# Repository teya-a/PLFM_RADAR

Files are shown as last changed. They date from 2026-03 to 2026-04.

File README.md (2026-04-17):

# AERIS-10: Open Source Pulse Linear Frequency Modulated Phased Array Radar







AERIS-10 is an open-source, low-cost 10.5 GHz phased array radar system featuring Pulse Linear Frequency Modulated (LFM) modulation. Available in two versions (3km and 20km range), it's designed for researchers, drone developers, and serious SDR enthusiasts who want to explore and experiment with phased array radar technology.

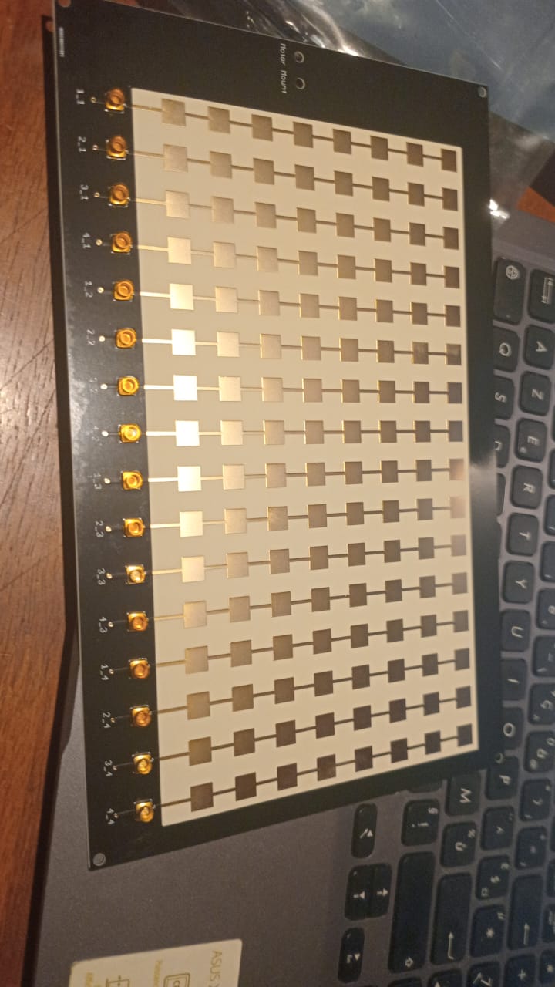
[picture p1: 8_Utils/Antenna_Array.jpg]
AERIS-10 Antenna Array


## 📡 Overview

The AERIS-10 project aims to democratize radar technology by providing a fully open-source, modular, and hackable radar system. Whether you're a university researcher, a drone startup, or an advanced maker, AERIS-10 offers a platform for experimenting with beamforming, pulse compression, Doppler processing, and target tracking.

## 🔬 Key Features

- **Open Source Hardware & Software** - Complete schematics, PCB layouts, firmware, and software available
- **Dual Version Availability**:
  - **AERIS-10N (Nexus)**: 3km range with 8x16 patch antenna array
  - **AERIS-10E (Extended)**: 20km range with 32x16 dielectric-filled slotted waveguide array
- **Full Electronic Beam Steering** - ±45° electronic steering in elevation and azimuth
- **Advanced Signal Processing** - On-board FPGA handles pulse compression, Doppler FFT, MTI, and CFAR
- **Python GUI** - User-friendly interface with map integration
- **GPS/IMU Integration** - Real-time position and attitude correction
- **Modular Design** - Separate power management, frequency synthesis, and RF boards

## 🏗️ System Architecture

AERIS-10 System Diagram

### Hardware Components

The AERIS-10 main sub-systems are:

- **Power Management Board** - Supplies all necessary voltage levels to the electronics components with proper filtering and sequencing (sequencing ensured by the microcontroller)

- **Frequency Synthesizer Board** - Uses a high-performance Low Jitter Clock Generator (AD9523-1) that supplies phase-aligned clock references for:
  - RX and TX Frequency Synthesizers (ADF4382)
  - DAC
  - ADC
  - FPGA

- **Main Board** containing:
  - **DAC** - Generates the RADAR Chirps
  - **2x Microwave Mixers (LT5552)** - For up-conversion and IF-down-conversion
  - **4x 4-Channel Phase Shifters (ADAR1000)** - For RX and TX chain beamforming
  - **16x Front End Chips (ADTR1107)** - Used for both Low Noise Amplifying (RX) and Power Amplifying (TX) stages
  - **XC7A50T FPGA** - Handles RADAR Signal Processing on the upstream FTG256 board:
    - PLFM Chirps generation via the DAC
    - Raw ADC data read
    - Automatic Gain Control (AGC)
    - I/Q Baseband Down-Conversion
    - Decimation
    - Filtering
    - Forward FFT
    - Pulse Compression
    - Doppler, MTI and CFAR processing
    - USB Interface
  - **STM32F746xx Microcontroller** - Used for:
    - Power-up and power-down sequencing (see Power Management Excel File)
    - FPGA communication
    - Setup and Interface with:
      - Clock Generator (AD9523-1)
      - 2x Frequency Synthesizers (ADF4382)
      - 4x 4-Channel Phase Shifters (ADAR1000) for RADAR pulse sequencing
      - 2x ADS7830 ADCs (on Power Amplifier Boards) for Idq measurement
      - 2x DAC5578 (on Power Amplifier Boards) for Vg control
      - GPS module for GUI map centering
      - GY-85 IMU for pitch/roll correction of target coordinates
      - BMP180 Barometer
      - Stepper Motor
      - 8x ADS7830 Temperature Sensors for cooling fan control
      - RF switches

- **16x Power Amplifier Boards** - Used only for AERIS-10E version, featuring 10Watt QPA2962 GaN amplifier for extended range

- **Antenna Arrays**:
  - **AERIS-10N (Nexus)** - 8x16 patch antenna array
  - **AERIS-10X (Extended)** - 32x16 dielectric-filled slotted waveguide antenna array

- **Miscellaneous Components**:
  - Slip-Ring
  - Stepper Motor and drivers
  - Cooling Fans
  - Enclosure

### Processing Pipeline

1. **Waveform Generation** - DAC creates LFM chirps
2. **Up/Down Conversion** - LT5552 mixers handle frequency translation
3. **Beam Steering** - ADAR1000 phase shifters control 16 elements
4. **Signal Processing (FPGA)**:
   - Raw ADC data capture
   - I/Q baseband down-conversion
   - Decimation & filtering (CIC/FIR)
   - Pulse compression
   - Doppler FFT processing
   - MTI & CFAR detection
5. **System Management (STM32)**:
   - Power sequencing
   - Peripheral configuration
   - GPS/IMU integration
   - Stepper motor control
6. **Visualization (Python GUI)**:
   - Real-time target plotting
   - Map integration
   - Radar control interface

AERIS-10 GUI Demo

## 📊 Technical Specifications

| Parameter | AERIS-10N (Nexus) | AERIS-10X (Extended) |
|---|---|---|
| **Frequency** | 10.5 GHz | 10.5 GHz |
| **Max Range** | 3 km | 20 km |
| **Antenna** | 8x16 Patch Array | 32x16 Slotted Waveguide |
| **Beam Steering** | Electronic (±45°) | Electronic (±45°) |
| **Mechanical Scan** | 360° (stepper motor) | 360° (stepper motor) |
| **Output Power** | ~1W×16 | 10W×16 (GaN amplifier) |
| **Processing** | FPGA + STM32 | FPGA + STM32 |

## 🚀 Getting Started

### 🧹 Repository File Placement Policy

To keep the repository root clean and make artifacts easy to find, place generated files in the following locations:

- **Published reports (tracked, GitHub Pages):** `docs/`
  - Example: `docs/AERIS_Simulation_Report_v2.pdf`
- **Simulation-generated outputs (local, gitignored):** `5_Simulations/generated/`
  - Plots, scenario outputs, temporary analysis directories
- **FPGA/Vivado generated artifacts (local, gitignored):** `9_Firmware/9_2_FPGA/reports/`
  - VCD/VVP dumps, temporary CSVs, local report snapshots
- **Reusable FPGA automation scripts (tracked):** `9_Firmware/9_2_FPGA/scripts/`
  - TCL flows, helper scripts used by build/bring-up

**Do not leave generated artifacts in the repository root.**

### Prerequisites

- Basic understanding of radar principles
- Experience with PCB assembly (for hardware build)
- Python 3.8+ for the GUI software
- FPGA development tools (Vivado) for signal processing modifications

### Hardware Assembly

1. **Order PCBs**: Production outputs are under `/4_Schematics and Boards Layout/4_7_Production Files`
2. **Source Components**: BOM/CPL files are co-located under `/4_Schematics and Boards Layout/4_7_Production Files`
3. **Assembly**: Use the schematics in `/4_Schematics and Boards Layout/4_6_Schematics` together with the production outputs above; a standalone assembly guide is not currently tracked
4. **Antenna**: Choose appropriate array files for your target variant
5. **Enclosure**: Mechanical drawings currently live in `/8_Utils/Mechanical_Drawings`

## 📜 License

This project is open-source but uses **different licenses for hardware and software** to ensure proper legal coverage.

### Hardware Documentation
The hardware design files—including:
- Schematics and PCB layouts (in `/4_Schematics and Boards Layout`)
- Bill of Materials (BOM) files
- Gerber files and manufacturing outputs
- Mechanical drawings and enclosure designs

are licensed under the **CERN Open Hardware Licence Version 2 – Permissive (CERN-OHL-P)** .

This is a hardware-specific license that:
- ✅ Clearly defines "Hardware," "Documentation," and "Products"
- ✅ Includes explicit patent protection for contributors and users
- ✅ Provides stronger liability limitations (important for high-power RF)
- ✅ Aligns with professional open-hardware standards (CERN, OSHWA)

You may use, modify, and sell products based on these designs, provided you:
- Maintain the original copyright notices
- Distribute any modified designs under the same license
- Make your modifications available in Source format

### Software and Firmware
The software components—including:
- FPGA code (VHDL/Verilog in `/9_Firmware`)
- Microcontroller firmware (STM32)
- Python GUI and utilities

remain under the **MIT License** for maximum flexibility.

### Full License Texts
- The complete CERN-OHL-P license text is in the `LICENSE` file
- MIT license terms apply to software where not otherwise specified

### Why This Change?
Originally, the entire project used the MIT license. The community (special thanks to gmaynez!) pointed out that MIT lacks legal protections needed for physical hardware. The switch to CERN-OHL-P ensures the project is properly protected while maintaining the same permissive spirit.

## 📚 Documentation

Comprehensive documentation is available in the `/docs` folder and served via GitHub Pages at [https://NawfalMotii79.github.io/PLFM_RADAR/docs/](https://NawfalMotii79.github.io/PLFM_RADAR/docs/):

- [System Architecture](/docs/architecture.html)
- [Implementation Log](/docs/implementation-log.html)
- [Hardware Bring-Up Guide](/docs/bring-up.html)
- [Test Reports](/docs/reports.html)
- [Release Notes](/docs/release-notes.html)

## 🤝 Contributing

We welcome contributions! Please see our [Contributing Guidelines](/CONTRIBUTING.md) for details on repo layout, branch workflow, and basic PR checks.

Areas where help is especially appreciated:
- **RF Engineers**: Review designs, optimize antenna performance
- **FPGA Developers**: Optimize signal processing pipeline
- **Software Developers**: Enhance Python GUI and SDK
- **Beta Testers**: University researchers, drone startups, advanced makers

## 📞 Contact & Collaboration

I welcome serious inquiries from researchers, engineers, and potential collaborators. However, due to the high volume of interest in this project, please understand that I cannot guarantee a response to every message.

- **Technical questions or bug reports**: Please [open a GitHub issue](https://github.com/NawfalMotii79/PLFM_RADAR/issues) so the whole community can benefit from the discussion.
- **Collaboration, licensing, or business inquiries**: 📧 nawfal.motii.33 [at] gmail [dot] com

## 💰 Sponsors

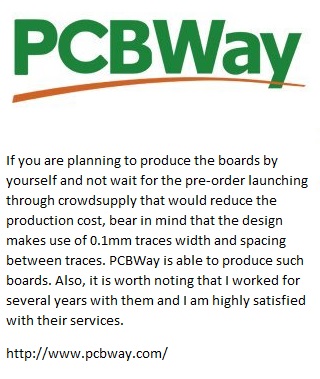
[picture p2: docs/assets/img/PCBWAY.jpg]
PCBWay Sponsor Logo


---

**Star ⭐ this repository if you're interested in open-source radar technology!**

*Note: This is an active development project. Some features are still in progress. Check the issues page for known limitations and upcoming features.*

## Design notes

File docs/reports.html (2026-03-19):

AERIS-10 Docs

Artifacts

# Published Reports and Visuals

Central access point for antenna simulations, implementation summaries, timing baselines, and board-day artifact references.

Open Board-Day Worksheet Open Bring-Up Plan

## Current FPGA implementation status

- Build 15 is the current detailed analysis baseline for the production XC7A200T target and completed with all timing constraints met.
- Build 16 was validated in the remote Vivado workspace as a constraint-cleanup pass: XDCB-5 warnings were removed, the large TIMING-18 bucket collapsed to a single ft601_txe methodology residue, and routed timing remained clean at WNS +0.058 ns, WHS +0.068 ns, WPWS +0.684 ns.
- The remaining ft601_txe methodology item currently behaves like an async-status-observation residue rather than a proven unconstrained functional FT601 path.

## Board-day artifact inventory

Artifact | Source path | Day-0 use | Status / note
Production-target XDC | 9_Firmware/9_2_FPGA/constraints/xc7a200t_fbg484.xdc | Constraint source of truth for the production FPGA target | Tracked and validated after Build 16 cleanup port
FPGA programming flow | 9_Firmware/9_2_FPGA/scripts/program_fpga.tcl | Programs the device and reports DONE / INIT_COMPLETE / probes presence | Primary operator-facing programming script
Debug probe insertion flow | 9_Firmware/9_2_FPGA/scripts/insert_ila_probes.tcl | Used when generating or refreshing debug-capable images | Keep matched with the selected debug bitstream
FPGA regression runner | 9_Firmware/9_2_FPGA/run_regression.sh | Pre-arrival regression evidence for the tracked FPGA baseline | 18 / 18 passing on the current tracked branch
MCU regression harness | 9_Firmware/9_1_Microcontroller/tests/Makefile | Pre-arrival firmware regression evidence before flashing hardware | 15 / 15 passing on the current tracked branch
Bring-up logging macros | 9_Firmware/9_1_Microcontroller/9_1_1_C_Cpp_Libraries/diag_log.h | Defines the main first-power-on log vocabulary used over USART3 | Observation-only instrumentation layer
Board-day worksheet | docs/board-day-worksheet.html | Record pass/fail, measurements, and blockers during first sessions | Use with this page and the bring-up plan
Bring-up execution plan | docs/bring-up.html | Operator checklist, abort criteria, observability targets, and open risks | Primary readiness document

## Antenna Simulation Report

Status: Mostly current (historical Phase-0 context)

File: AERIS_Antenna_Report.pdf

Notes: Valid for 10.5 GHz patch-element simulation and array projection context. Treat as element-level evidence, not full current hardware bring-up sign-off.

Open PDF Download

## Python Simulation Report

Status: Legacy (needs refresh)

File: AERIS_Simulation_Report.pdf

Notes: Contains older architecture assumptions (e.g., XC7A100T-centric narrative). Use as historical reference only until Simulation Report v2 is published.

Open PDF Download

## FPGA implementation analysis

Status: Current engineering baseline

Primary detailed write-up: internal Build 15 implementation analysis captured timing, power, route status, DRC, methodology, CDC, and utilization for the production-target design after USB range wiring and CFAR cleanup.

Follow-on Build 16 remote validation focused on production XDC cleanup only and confirmed no timing regression while reducing methodology noise substantially.

## Latest Simulation Report (Recommended)

Status: Current baseline (v2)

File: AERIS_Simulation_Report_v2.pdf

Aligned to the active project baseline: XC7A200T target, firmware regression closure, FPGA regression/timing gates, USB range-profile integration, and TE0712/TE0713 split-target flow.

Open PDF Download

## Report Currency Notice

- The current routed production-target baseline is Build 15, with Build 16 used as a remote-only XDC cleanup validation pass.
- The latest public simulation PDF should be interpreted alongside the implementation log and release notes for the most accurate state of firmware bug closure and FPGA integration readiness.
- Detailed Build 15 and Build 16 engineering notes currently live in internal working reports and remote Vivado artifacts rather than this public docs directory.
- The artifact inventory above is intended to stabilize day-0 execution even when the detailed internal engineering reports stay outside the public docs site.

## Antenna concept snapshot

Antenna array concept

Add future report artifacts here to keep public references stable.

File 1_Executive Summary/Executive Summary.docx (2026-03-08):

TITLE: Open Source Pulse Linear Frequency Modulated Phased Array RADAR
Reference:
Date:
Original Proposal Date:

## 1.0 PROJECT DESCRIPTION

An open-source, low-cost 10.5 GHz phased array radar with phased array antenna and Pulse LFM modulation—available in 3km and 20km range versions. For researchers, drone developers, and serious SDR enthusiasts.

## 2.0 TECHNICAL SPECIFICATIONS

### 2.1 System Architecture Overview

- The AERIS-10 comes in 2 versions:
  - AERIS-10N (Nexus) with Range up to 3Km
  - AERIS-10X (Extended) with scanning Range up to 20Km
- Frequency: 10.5GHz
- Antenna Type: 8x16 patch antenna array for the Nexus and 32x16 dielectric-filled slotted waveguide antenna array for the Extended version.
- Electronically controlled Elevation and Azimuth Beam steering. (The prototype uses the 16 antenna elements to steer the Azimuth beam and the Elevation is performed using a stepper motor; but the designed system can be hacked to control both Elevation and Azimuth electronically.
- Output: Range & Doppler of Multi-Targets
- Interface: A GUI written in Python

Current Status: Alpha Prototype

For sake of testing, validating and optimizing the cost of the prototype, this late has been designed using one PCB for:
- The Power supply management
- The Digital components
- The Analog and mixed signal components
- The RF parts

This won’t be the case for the mass production system, where separated modules would be used to reduce EMI and enhance the signals integrity; also a more professional clock source and frequency synthesizer would be used. The new schematics, PCB layout and firmware are already available

Understanding the System Hardware:

The AERIS-10 main sub-systems are:

- A Power Management Board that supplies all the necessary voltage levels to the electronics components with proper filtering and sequencing (This late is ensured by the microcontroller)
- A Frequency Synthesizer Board using a high performance Low Jitter Clock Generator (AD9523-1) that supplies phased aligned clock references for the:
  - RX and TX Frequency Synthesizers (ADF4382)
  - DAC
  - ADC
  - FPGA
- A Main Board containing:
  - A DAC to generate the RADAR Chirps
  - 2 Microwave Mixers (LT5552) for up-conversion and IF-down-conversion
  - 4 4-Channels Phase Shifters (ADAR1000) for the RX and TX chain
  - 16 Front End chips (ADTR1107) used for Both Low Noise Amplifying (RX) and Power Amplifying (TX) Stages
  - An XC7A100T FPGA used for RADAR Signal Processing:
    - PLFM Chirps generation via the DAC
    - Raw ADC data read
    - AGC
    - I/Q Baseband Down-Conversion
    - Decimation
    - Filtering
    - Forward FFT
    - Pulse Compression
    - Doppler, MTI and CFAR processing
    - USB Interface
  - An STM32F746xx Microcontroller used to:
    - Ensure the proper powering up and down sequencing (Check the Power Management Excel File)
    - Communicate with the FPGA
    - Setup and Interface with the following components:
      - The Clock Generator (AD9523-1)
      - The 2 Frequency Synthesizers (ADF4382)
      - The 4 4-Channels Phase Shifters (ADAR1000) for proper RADAR pulse sequencing
      - The 2 ADS7830 ADCs used on the 16 Power Amplifier Boards to measure Idq
      - The 2 DAC5578 used on the 16 Power Amplifier Boards to control Vg
      - The GPS used to set the center of the map on the GUI
      - The GY_85 IMU to apply pitch and roll correction to the processed target longitude and latitude
      - The BMP180 Barometer
      - The Stepper Motor
      - The 8 ADS7830 Temperature Sensors used to activate the Cooling Fans
      - RF switches
- 16 Power Amplifier Boards used only for the AERIS-10E where a 10Watt QPA2962 GaN amplifier has been chosen to extend the RADAR Range
- 8x16 patch antenna array board for the Nexus and 32x16 dielectric-filled slotted waveguide antenna array for the Extended version
- Miscellaneous (Slip-Ring, Stepper Motor and its drivers, Cooling Fan, Enclosure…)

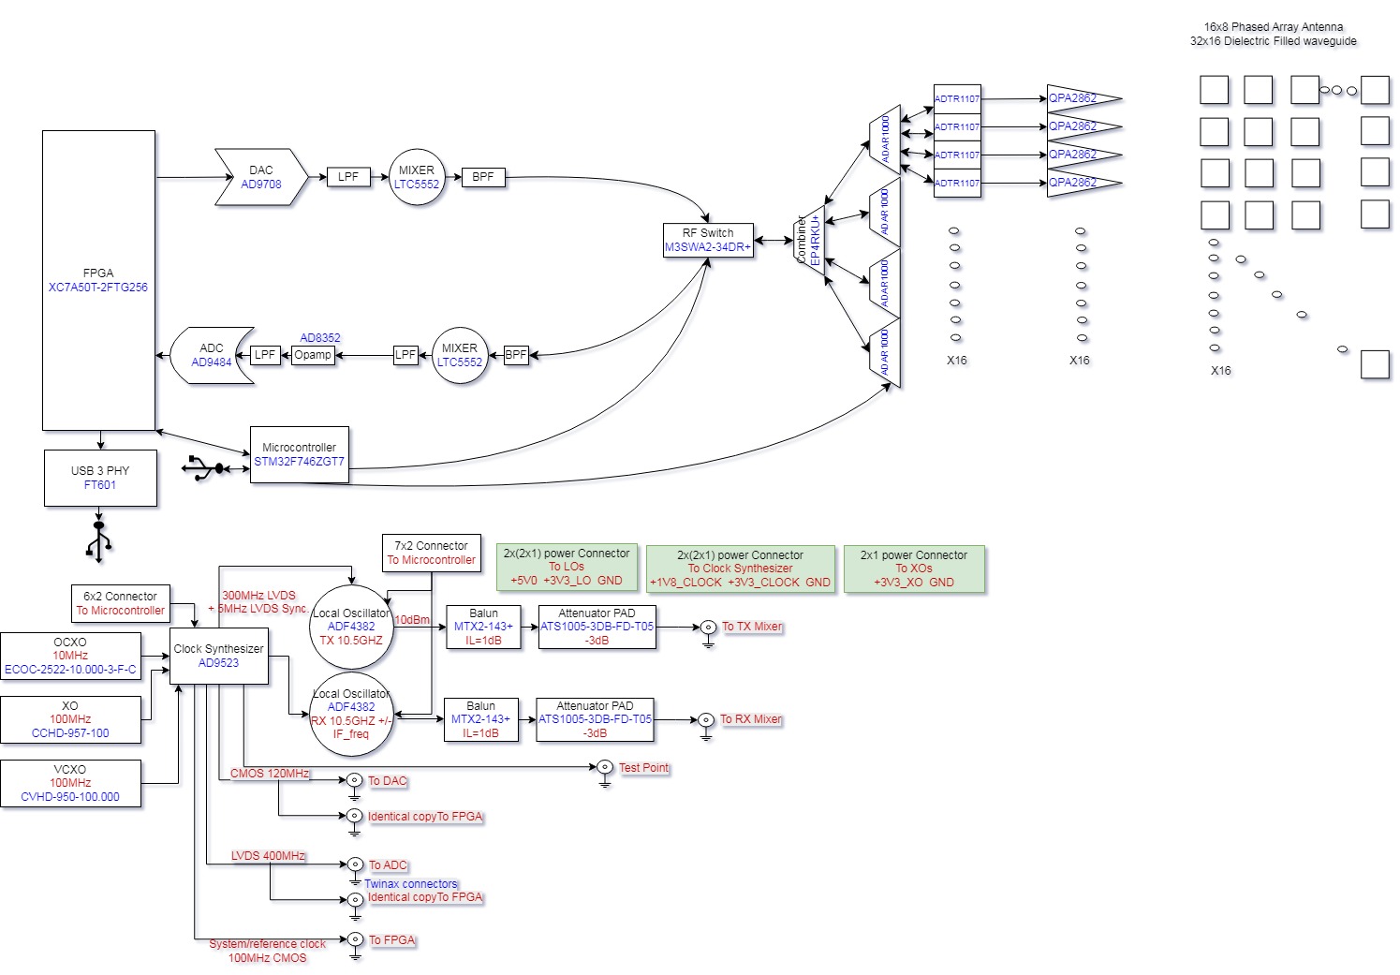
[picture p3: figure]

### 2.4 Software & Processing

The AERIS-10 radar system is built around three core processing elements working in concert: an STM32 microcontroller handling system management and peripherals, an FPGA executing real-time signal processing, and a Graphical User Interface (GUI) for user control and data visualization. The following describes the complete boot sequence and operational loop that governs how the system wakes, calibrates, and begins scanning.

### System Boot and Initialization

When power is first applied, the STM32 microcontroller begins a carefully sequenced startup routine designed to bring all subsystems online in the correct order, ensuring stable power and clock references before any RF activity begins.

The first critical step is waiting for the OCXO (Oven-Controlled Crystal Oscillator) to reach thermal stability. This high-precision frequency reference requires approximately three minutes to warm up and stabilize—without this wait, the entire radar's frequency accuracy would drift, compromising range resolution and target detection.

Once the OCXO is stable, the STM32 manages voltage sequencing for the system's clock generator, the AD9523. This ensures that power rails reach their correct levels in the proper order before the device is initialized. The STM32 then configures the AD9523, setting up the planned clock distribution that will drive the FPGA and all RF components with precise, phase-aligned timing.

With clocks established, the STM32 sequences power for the FPGA itself, then proceeds to initialize the remaining peripheral systems:

- The GPS module begins acquiring satellite locks
- The IMU (Inertial Measurement Unit) and barometer are initialized for attitude and altitude sensing
- Two ADF4382 frequency synthesizers (one for transmit, one for receive) are configured
- Four ADAR1000 beamforming chips are initialized to control the 16 phased array elements

At this point, all hardware is ready and the system enters a waiting state, listening for the start command from the GUI.

### GUI Connection and System Arming

The operator interacts with the system through a custom Graphical User Interface running on a connected computer. When the user is ready to begin operation, they press the Start button on the GUI.

The GUI immediately transmits a specific start flag packet to the STM32—a predefined sequence of bytes {23, 46, 158, 237} that serves as a handshake to confirm communication is established. Following this flag, the GUI sends the full operational settings for the upcoming radar scan (waveform parameters, scan pattern, range settings, etc.).

The STM32 acknowledges these settings and begins actively monitoring the GPS data stream. It waits for a valid data lock, then begins sending modulated position streams back to the GUI containing longitude, latitude, and altitude information. The GUI receives these streams and uses the coordinates to center its map display on the radar's current location—giving the operator immediate spatial context for any detected targets.

### Attitude Determination and Mechanical Alignment

While maintaining GPS position updates, the STM32 continuously reads raw data from the IMU and barometer. It processes the IMU data to calculate pitch, roll, and yaw angles, while the barometer provides a secondary altitude reference.

With yaw (heading) known, the STM32 commands the stepper motor to rotate the antenna assembly to align with yaw = 0° (typically true north or a defined reference). This mechanical alignment ensures that all subsequent electronically-steered beams are referenced to a consistent absolute direction.

### Transmit and Receive Chain Configuration

Before any radar pulses are sent, the RF front-end must be precisely tuned. The STM32 configures the two ADF4382 frequency synthesizers—one set to the transmit frequency, the other to the receive frequency. Critically, it then executes a phase synchronization routine between these two synthesizers, ensuring that transmit and receive local oscillators are phase-coherent. This coherence is essential for Doppler processing and coherent pulse compression.

### The Scanning Loop: A Three-Level Nested Structure

The AERIS-10's scanning pattern is organized as a three-level nested loop, controlling:

1. Chirp sequence index (m) – Individual frequency ramps within a burst
2. Beam steering index (n) – Electronic steering across 32 elevation/azimuth positions
3. Mechanical azimuth index (y) – Physical rotation across 50 positions per revolution

This structure allows the system to build a complete volumetric scan through a combination of electronic beam steering (fast, within the pulse repetition interval) and mechanical rotation (slow, covering 360 degrees).

#### Loop Variables Defined

- m = Chirp number within a burst. Each burst consists of 32 chirps, organized as: *16 chirps at PRF1 (pulse repetition frequency 1) with duration T1, followed by a guard interval of 175.4µs, then 16 chirps at PRF2 with duration T2*
- n = Electronic steering index, ranging from 1 to 32. This corresponds to beam positions in elevation (or azimuth, depending on scan mode), controlled by phase settings on the ADAR1000 beamforming chips.
- y = Mechanical azimuth index, ranging from 1 to 50. The stepper motor moves the antenna to 50 discrete positions per full revolution, providing mechanical scanning in azimuth while electronics handle fast steering in the orthogonal plane.

### The Operational Loop

The loop begins with the STM32 commanding the stepper motor to move to the first azimuth position (y=1). Once the mechanical position is settled:

1. The STM32 sets the ADAR1000 phase shifters to the values corresponding to beam position n
2. It manages voltage sequencing for the ADTR1107s (RF switches) and the RF power amplifiers, ensuring they power up cleanly
3. It sends a flag to the FPGA indicating transmit mode and configures the ADAR1000s for transmission
4. The FPGA generates the chirp waveform through its DAC, driving the transmit array
5. Immediately after transmission, the FPGA signals the STM32 to switch to receive mode
6. The STM32 reconfigures the ADAR1000s for reception
7. The FPGA captures the returning echoes through its ADCs and begins the signal processing pipeline:
  - Down-conversion of the IF signal to baseband
  - Filtering
  - Extraction of I/Q components (using CIC filters, FIR filters, and NCO)
  - Pulse compression
  - Per-range Doppler FFT
  - Moving Target Indication (MTI)
  - Constant False Alarm Rate (CFAR) detection
  - Emission of detection reports (including small Range-Doppler thumbnails)
8. Processed radar data is sent from the FPGA to the GUI via FTDI interface
9. The GUI receives the data and updates its plots in real-time, displaying detected targets overlaid on the map

### Loop Iteration and Scan Completion

After completing the processing for chirp m, the system increments m and returns to step 34 (DAC chirp generation). This continues until m exceeds 32, at which point:

- m resets to 1
- n increments (move to next electronic beam position)
- The loop returns to step 29 (set new ADAR1000 phase values)

When n exceeds 32 (all electronic beam positions completed), then:

- n resets to 1
- y increments (move stepper motor to next mechanical azimuth position)
- If y exceeds 50 (full revolution completed), y resets to 1 and the scan continues indefinitely or until stopped by the operator

This continuous loop builds a complete 3D radar picture, with electronic steering providing fast elevation/azimuth coverage and mechanical rotation providing full 360-degree azimuth scanning.

### Summary

The AERIS-10's operational flow represents a sophisticated orchestration of multiple subsystems:

- STM32 handles the "conductor" role—sequencing power, configuring peripherals, managing the stepper motor, and coordinating mode switches
- FPGA executes the "orchestra"—generating waveforms, capturing echoes, and running the intense signal processing pipeline
- GUI provides the "audience view"—displaying maps, targets, and enabling operator control

This division of labor allows each processor to focus on what it does best, creating a coherent, high-performance radar system that remains flexible and programmable through its open architecture.

What's Working:

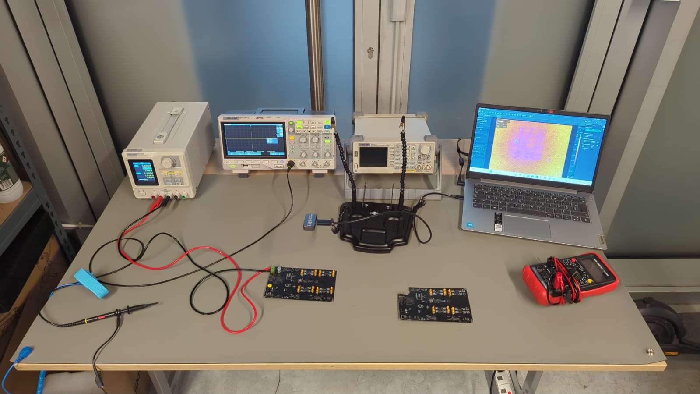
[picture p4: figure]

- Beam formation from 16x8 array
- Electronic steering ±45° elevation
- Pulse LFM generation and reception
- Basic target detection to 1km
- Raw data capture and processing via the FPGA:
  - FM Chirp generation via the DAC
  - Raw ADC data read
  - AGC
  - I/Q Base Band Down-Conversion
  - Decimation
  - Filtering
  - Forward FFT
  - Pulse Compression
  - Doppler, MTI and CFAR processing

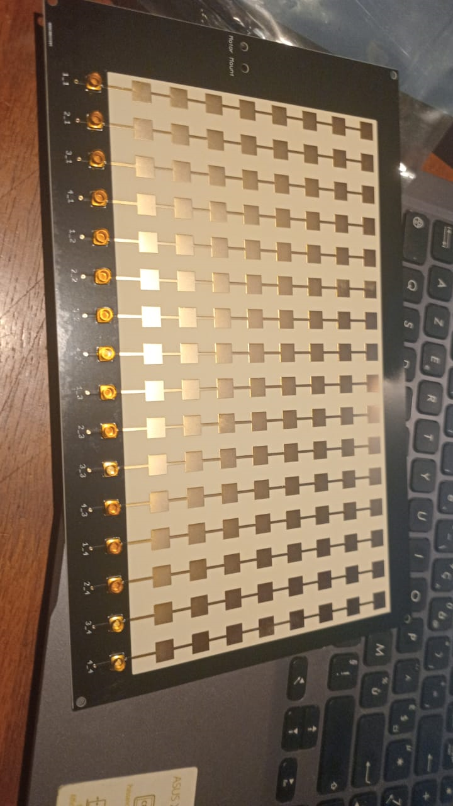
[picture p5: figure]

What's in Progress:

- Performing the RADAR processing using the python GUI rather than the FPGA and benchmarking the 2 approaches.
- Using multiple synchronized RADAR boards to enhance the beam steering resolution and Range.
- Crowd funding campaign launch

Get Involved:

I'm actively seeking:

- Beta testers: (university researchers, drone startups, advanced makers)

- RF engineers to review designs

- FPGA developers for signal processing optimization

- Software developers for the Python/C++ SDK

ABAC INDUSTRY SARL AU /R.C. n° 515463 / I.T.P. n° 34262538 / n° ICE 002911762000053 / IF n° 50499079 Adresse: 46 BD ZERKTOUNI ETG 5 N17 CO DOWORK CASABLANCA MAROC Tel: +212 (0) 786433177 email: nawfal.motii.33@gmail.com

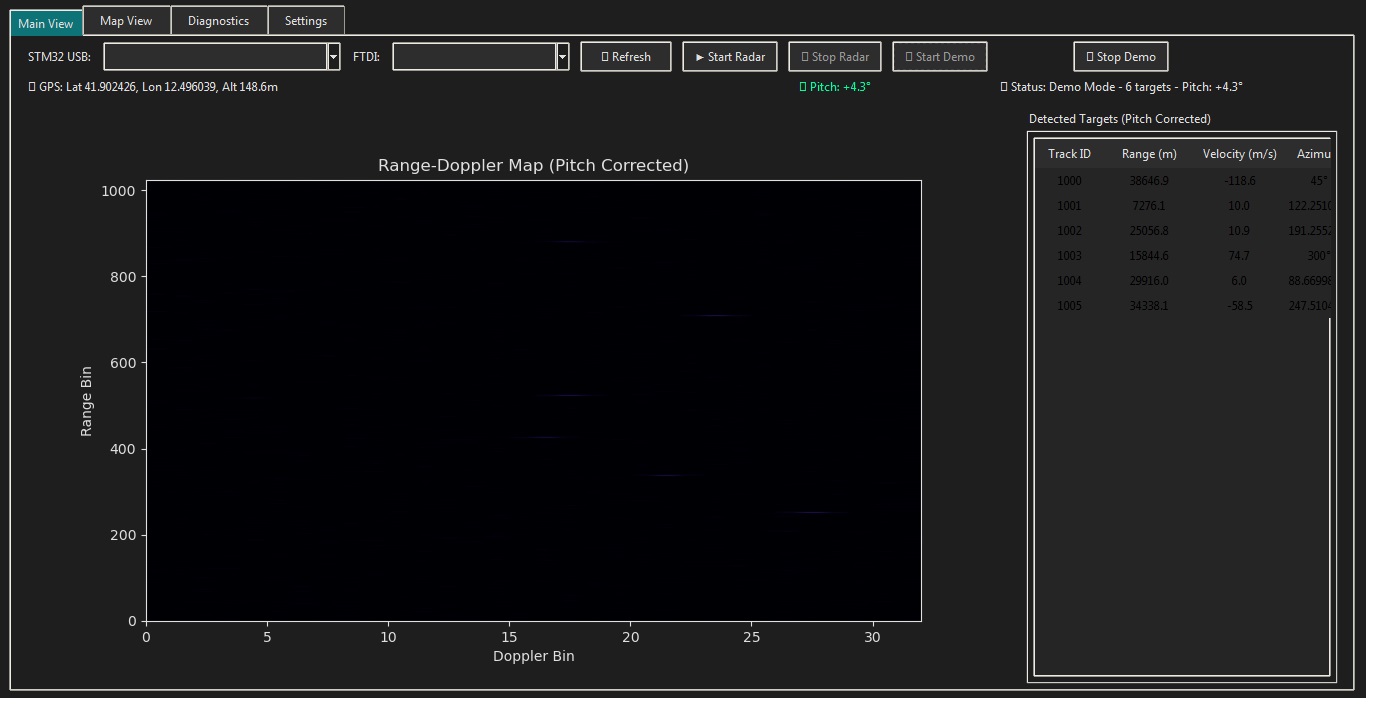
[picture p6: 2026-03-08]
docs/assets/img/GUI.jpg

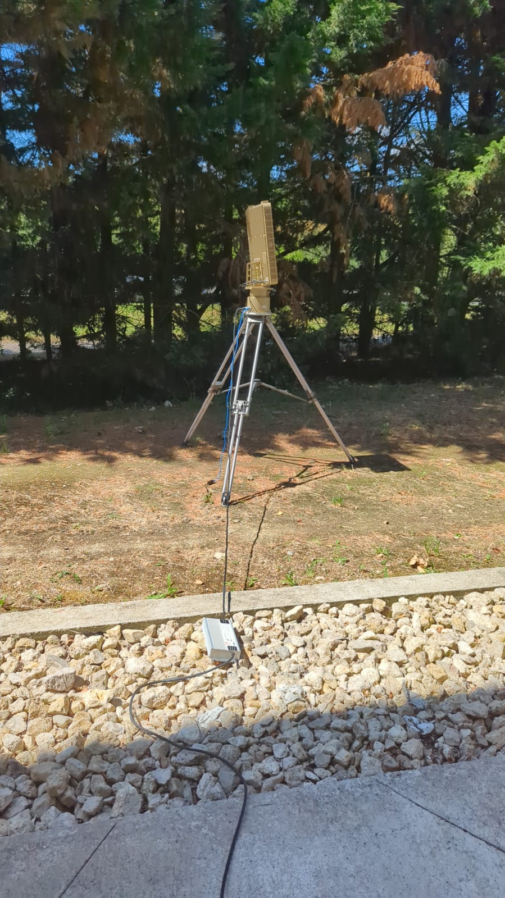
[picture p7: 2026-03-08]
docs/assets/img/3fb1dabf-2c6d-4b5d-b471-48bc461ce914.jpg

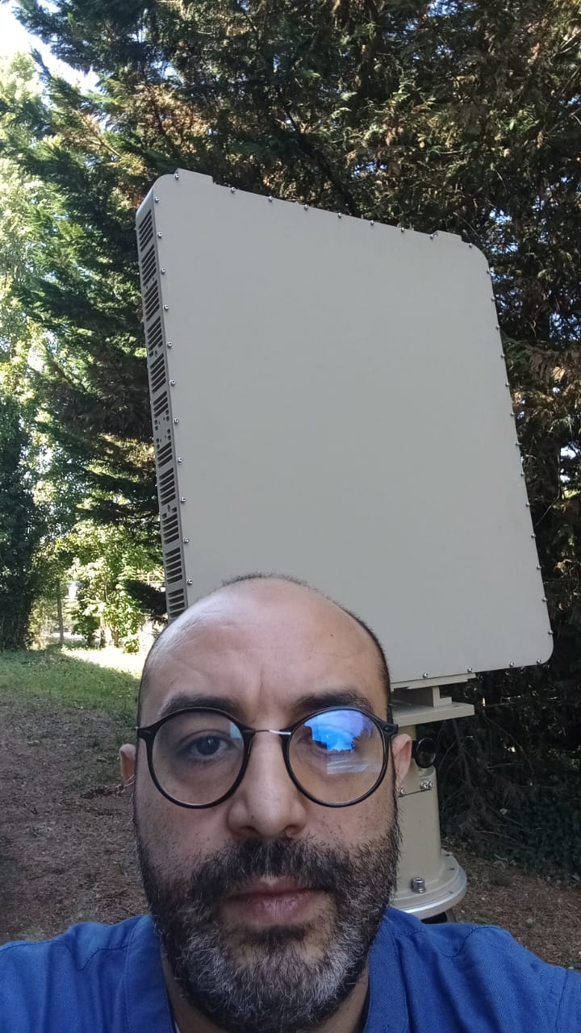
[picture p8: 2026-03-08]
docs/assets/img/b79a6fe3-5abf-473d-b3e2-178e6a9cf4da - Copie.jpg

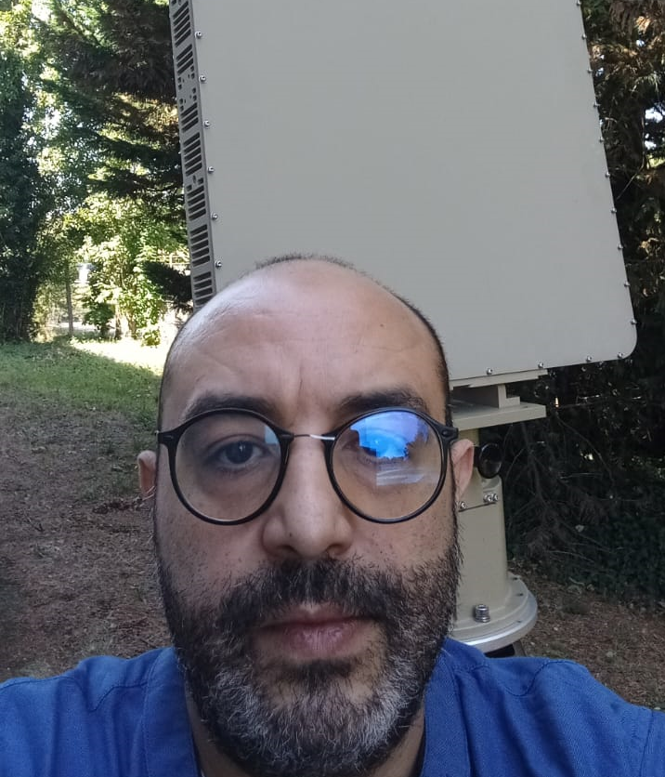
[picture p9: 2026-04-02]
docs/assets/img/Nawfal.png

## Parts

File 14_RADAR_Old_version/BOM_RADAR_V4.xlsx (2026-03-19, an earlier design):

Qty | Value | Device | Package | Parts | Description | MANUFACTURER_PART_NUMBER
1 |  | PINHD-1X6 | 1X06 | JP2 | PIN HEADER | M20-9990645
1 |  | PINHD-2X4 | 2X04 | JP3 | PIN HEADER | 67997-208HLF
24 | 0.1uF | CC0201 | C0201 | C38, C39, C41, C42, C43, C44, C45, C47, C49, C53, C54, C57, C80, C82, C159, C188, C189, C190, C192, C193, C194, C195, C198, C201 | CAPACITOR, European symbol | CL03A104KP3NNNH
12 | 0.47uF | CC0201 | C0201 | C110, C111, C112, C113, C155, C156, C157, C158, C179, C180, C181, C182 | CAPACITOR, European symbol | CL03A474KP3NNNC
4 | 0.4pF | CC0201 | C0201 | C125, C163, C183, C202 | CAPACITOR, European symbol | CC0201BRNPO9BNR40
1 | 0R | RR0201 | R0201 | R44 | RESISTOR, European symbol | RC0201JR-070RL
12 | 1.5ｵH | 2.2ｵH_SHIELDED_INDUCTOR | 806 | L1, L2, L3, L4, L9, L10, L11, L12, L13, L14, L15, L17 | Murata 2.2uH Inductor | LQM2MPN1R5MGHL
1 | 1.9k | RR0201 | R0201 | R35 | RESISTOR, European symbol | ERJ-1GNF1911C
1 | 100R | RR0201 | R0201 | R40 | RESISTOR, European symbol | RC0201FR-07100RL
12 | 100nF | CC0201 | C0201 | C24, C25, C26, C27, C28, C29, C30, C32, C33, C34, C35, C50 | CAPACITOR, European symbol | CL03A104KP3NNNH
2 | 100pF | CC0201 | C0201 | C79, C81 | CAPACITOR, European symbol | 0201CG101J500NT
1 | 100ｵF | UCD1H101MNL1GS | PCAP_8X10-ELECT_NCA | C36 |  | UCD1H101MNL1GS
33 | 10k | RR0201 | R0201 | R4, R5, R6, R7, R10, R12, R14, R19, R20, R21, R22, R83, R84, R85, R86, R89, R91, R93, R95, R97, R98, R99, R100, R101, R103, R105, R107, R108, R109, R111, R120, R121, R145 | RESISTOR, European symbol | AC0201FR-0710KL
17 | 10nF | CC0201 | C0201 | C74, C102, C103, C104, C105, C106, C107, C114, C115, C116, C117, C118, C119, C120, C121, C122, C123 | CAPACITOR, European symbol | 0201B103K250NT
1 | 10pF | CC0201 | C0201 | C73 | CAPACITOR, European symbol | CL03C100JA3GNNC
2 | 10uF | CC0201 | C0201 | C37, C40 | CAPACITOR, European symbol | KGM03DS60E106MH
2 | 12pF | CC0201 | C0201 | C184, C185 | CAPACITOR, European symbol | 0201CG120J500NT
14 | 15pF | CC0201 | C0201 | C14, C133, C135, C137, C139, C146, C148, C150, C152, C161, C162, C167, C196, C197 | CAPACITOR, European symbol | 0201CG150J500NT
2 | 17.8R | RR0201 | R0201 | R18, R124 | RESISTOR, European symbol | ERJ-1GNF17R8C (https://eu.mouser.com/ProductDetail/Panasonic/ERJ-1GNF17R8C?qs=nuXzIS8loXGBClA5eWf9Pg%3D%3D)
3 | 18pF | CC0201 | C0201 | C12, C75, C77 | CAPACITOR, European symbol | TCC0201COG180J500ZT
14 | 1k | RR0201 | R0201 | R15, R16, R34, R36, R37, R55, R56, R57, R58, R61, R138, R139, R140, R144 | RESISTOR, European symbol | RC0201FR-071KL
1 | 1k2_1% | RR0201 | R0201 | R60 | RESISTOR, European symbol | RC0201FR-071K2L
2 | 1nF | CC0201 | C0201 | C199, C200 | CAPACITOR, European symbol | CL03B102KA3NNNC
3 | 1pF | CC0201 | C0201 | C83, C84, C85 | CAPACITOR, European symbol | 0201CG1R0C250NT
25 | 1uF | CC0201 | C0201 | C7, C60, C68, C69, C70, C76, C78, C86, C87, C88, C89, C90, C91, C92, C93, C94, C95, C96, C97, C98, C99, C100, C101, C131, C145 | CAPACITOR, European symbol | CL03A105KP3NSNC
1 | 2.2k | RR0201 | R0201 | R146 | RESISTOR, European symbol | RC0201FR-072K2L
7 | 2.2uF | CC0201 | C0201 | C22, C23, C46, C48, C51, C52, C164 | CAPACITOR, European symbol | GRM033R61A225KE47D
4 | 2.5nH | LL0201 | L0201 | L16, L24, L26, L27 | INDUCTOR, European symbol | MLG0603P2N5CT000 (https://eu.mouser.com/ProductDetail/TDK/MLG0603P2N5CT000?qs=u4%252BEJ9urDAR2nL3QJhoJtw%3D%3D)
2 | 2.7pF | CC0201 | C0201 | C18, C19 | CAPACITOR, European symbol | CL03C2R7CA
3 | 20k | RR0201 | R0201 | R2, R8, R88 | RESISTOR, European symbol | RC0201FR-0720KL
1 | 20pF | CC0201 | C0201 | C71 | CAPACITOR, European symbol | CC0201JRNPO9BN200
13 | 22R | RR0201 | R0201 | R23, R24, R25, R26, R27, R28, R29, R30, R49, R51, R62, R63, R64 | RESISTOR, European symbol | RC0201FR-0722RL
9 | 23k | RR0201 | R0201 | R13, R82, R90, R92, R94, R96, R102, R104, R106 | RESISTOR, European symbol | WR02X2302FAL
4 | 25R | RR0201 | R0201 | R59, R152, R154, R161 | RESISTOR, European symbol | RK73H1HRTTCM25R5F
4 | 294R | RR0201 | R0201 | R17, R122, R123, R125 | RESISTOR, European symbol | CRCW0201294RFKED (https://eu.mouser.com/ProductDetail/Vishay-Dale/CRCW0201294RFKED?qs=3bSaU8eFeoGaWlAbeLzCtQ%3D%3D)
1 | 2k | RR0201 | R0201 | R9 | RESISTOR, European symbol | RC0201FR-072KL
2 | 3.2nF | CC0201 | C0201 | C127, C141 | CAPACITOR, European symbol | 02016C332KAT2A (https://eu.mouser.com/ProductDetail/KYOCERA-AVX/02016C332KAT2A?qs=O2%2FeDh0sX9zXSyMYjJs4ZQ%3D%3D)
1 | 3.3uF | CC0201 | C0201 | C191 | CAPACITOR, European symbol | CM03X5R475M06AH055 (https://eu.mouser.com/ProductDetail/KYOCERA-AVX/CM03X5R475M06AH055)
1 | 30R | RR0201 | R0201 | R42 | RESISTOR, European symbol | RC0201FR-0730RL
2 | 30nH | LL0201 | L0201 | L21, L23 | INDUCTOR, European symbol | LQP03TN30NH02D
1 | 330R | RR0201 | R0201 | R43 | RESISTOR, European symbol | RC0201FR-07330RL
1 | 33pF | CC0201 | C0201 | C72 | CAPACITOR, European symbol | TCC0201COG330K500ZT
1 | 3k2 | RR0201 | R0201 | R33 | RESISTOR, European symbol | ERJ-1GNF3241C
2 | 4.3pF | CC0201 | C0201 | C20, C21 | CAPACITOR, European symbol | 0201CG4R3C500NT
27 | 4.7k | RR0201 | R0201 | R45, R46, R47, R48, R50, R52, R53, R54, R65, R66, R67, R68, R69, R70, R71, R72, R73, R74, R75, R76, R77, R117, R118, R119, R141, R142, R143 | RESISTOR, European symbol | RC0201FR-074K7L
28 | 4.7uF | CC0201 | C0201 | C2, C4, C5, C6, C8, C56, C58, C59, C61, C62, C63, C64, C65, C66, C67, C108, C109, C128, C129, C130, C132, C142, C143, C144, C153, C154, C177, C178 | CAPACITOR, European symbol | GRM035R60J475ME15D
2 | 4.7uF 35V | 4.7UF-POLAR-EIA3528-35V-10%(TANT) | EIA3528 | C186, C187 |  | KGM31AR71H475KU
1 | 47nF | CC0201 | C0201 | C31 | CAPACITOR, European symbol | TCC0201X5R473K160ZT
4 | 47uF | 47UF-POLAR-0603-6.3V-20%(TANT) | 0603-POLAR | C3, C15, C16, C124 | 10.0ｵF polarized capacitors | TLCL476M006RTA
15 | 47uF | CC0201 | C0201 | C1, C9, C11, C13, C17, C55, C126, C134, C136, C138, C140, C147, C149, C151, C176 | CAPACITOR, European symbol | T495C226K010AHE245
9 | 500R | RR0201 | R0201 | R38, R41, R110, R112, R113, R114, R151, R153, R159 | RESISTOR, European symbol | ERJ-1GNF4990C
12 | 50R | RR0201 | R0201 | R31, R39, R115, R116, R147, R148, R149, R150, R155, R156, R157, R158 | RESISTOR, European symbol | TNPR020150R0DEED
1 | 525R | RR0201 | R0201 | R32 | RESISTOR, European symbol | CRCW0201523RFNED
3 | 5k | RR0201 | R0201 | R1, R3, R87 | RESISTOR, European symbol | WR02X4991FAL
16 | 60124102122403 | 60124102122403 | 60124102122403 | J1, J2, J3, J4, J5, J6, J7, J8, J9, J10, J11, J12, J13, J14, J15, J16 | WR-SMP Straight | 60124102122403
1 | 691137910002 | 691137910002 | 691137910002 | J17 | Wurth Elektronik 1379, 2 Way PCB Terminal Block | 691137910002
1 | 6pF | CC0201 | C0201 | C165 | CAPACITOR, European symbol | 0201CG6R0C250NT
2 | 75nH | LL0201 | L0201 | L8, L18 | INDUCTOR, European symbol | LQP03TN75NJ02D
1 | 75pF | CC0201 | C0201 | C10 | CAPACITOR, European symbol | GRM0335C1H750GA01D
4 | 840R | RR0201 | R0201 | R78, R79, R80, R81 | RESISTOR, European symbol | CPF0201B845RE1
1 | 8k | RR0201 | R0201 | R11 | RESISTOR, European symbol | RT0201BRE078K06L
2 | 8.2nH | LL0201 | L0201 | L22, L25 | INDUCTOR, European symbol | 7447820082G (https://eu.mouser.com/ProductDetail/Wurth-Elektronik/7447820082G?qs=aP1CjGhiNiFWFKHJCgy3WQ%3D%3D)
1 | AD9708AR | AD9708AR | RW_28_ADI | U3
4 | ADAR1000ACCZN | ADAR1000ACCZN | CC-88-1_ADI | GND, U18, U19, U20
1 | ADF4382ABCCZ | ADF4382ABCCZ | CC-48-10_ADI | U7
16 | ADTR1107ACCZ | ADTR1107ACCZ | CC-24-8_ADI | U21, U22, U23, U24, U25, U26, U27, U28, U29, U30, U31, U32, U33, U34, U35, U36
1 | AT93C46A-10SQ-2.7 | AT93C46A-10SQ-2.7 | SOIC8 | IC1 | Three-wire Automotive Temperature Serial EEPROM 1K (64 x 16)
5 | BLM15HB121SN1 | BLM15HB121SN1 | 402 | L5, L6, L7, L19, L20 | EMIFIL (R) Chip Ferrite Bead for GHz Noise
2 | BPF2 | BPF2 | BPF2 | U$2, U$3
5 | Blue | LED-BLUE0603 | LED-0603 | D1, D2, D3, D4, D5 | Blue SMD LED
1 | CX3225SB25000D0FLJCC | CX3225SB25000D0FLJZ1 | XTAL4_CX3225SB_AVX | XTAL4
1 | ECS-120-10-36B2-JTN-TR | CRYSTAL-12MHZ | CRYSTAL-SMD-2X2.5MM | Y1 | 12.0MHz Crystal
1 | EP4RKU+ | EP4RKU+ | DG1677-2_MNC | U16
1 | FAN | PINHD-1X2 | 1X02 | JP4 | PIN HEADER
1 | FT2232HQ | FT2232HQ | 64QFN_FT2232HQ_FTD | U6
1 | LCD | PINHD-1X4 | 1X04 | JP5 | PIN HEADER
2 | LM2662MX/NOPB | LM2662MX/NOPB | M08A | U8, U37
2 | LTC5552IUDBTRMPBF | LTC5552IUDBTRMPBF | UDB_12_ADI | U5, U13
1 | LTC6419IV#PBF | LTC6419IV#PBF | LTC6419IVPBF | IC2 | SP Amp DIFF AMP Dual 5.25V 20-Pin LGA Tray
1 | M3SWA2-34DR+ | M3SWA2-34DR+ | 16_QFN | U$1
1 | MAX1449EHJ+ | MAX1449EHJ+ | 21-0110B_MXM | U4
3 | MAX20029ATIA/V+ | MAX20029ATIA/V+ | 21-0140L_T2855-5_MXM | U1, U38, U39
1 | MINI-USB-32005-201 | MINI-USB-32005-201 | 32005-201 | X2 | MINI USB-B Conector | 1734035-3
1 | MOMENTARY-SWITCH-SPST-SMD-4.6X2.8MM | MOMENTARY-SWITCH-SPST-SMD-4.6X2.8MM | TACTILE_SWITCH_SMD_4.6X2.8MM | S1 | Momentary Switch (Pushbutton) - SPST
1 | MT25QL01GBBB8E12-0AUT | MT25QL01GBBB8E12-0AUT | BGA24_MT25QL_MRN | U9
2 | MTX2-143+ | MTX2-143+ | DQ1225_MNC | U11, U12
1 | NX3215SA-32.768KHz | NX3225GD-8MHZ-STD-CRA-3 | XTAL_NX3225GD-8MHZ-STD-CRA-3_N | XTAL3
1 | NX3225GD-8MHZ-STD-CRA-3 | NX3225GD-8MHZ-STD-CRA-3 | XTAL_NX3225GD-8MHZ-STD-CRA-3_N | XTAL1
1 | SI5351A-B-GM | SI5351A-B-GM | QFN20_SIL | U10
1 | STM32F746ZGT7 | STM32F746ZGT7 | LQFP-144_STM | U2
2 | SZMMSZ5232BT1G | SZMMSZ5232BT1G | SOD-123_ONS | U14, U15
18 | TP | TEST-POINT2 | PAD.02X.02 | TP1, TP2, TP3, TP4, TP5, TP6, TP7, TP8, TP9, TP10, TP11, TP12, TP13, TP14, TP15, TP16, TP17, TP18 | SparkFun Test Points
1 | XC7A50T-2FTG256I | XC7A50T-2FTG256I | BGA256C100P16X16_1700X1700X155 | U42 | Artix-7 Field Programmable Gate Array (FPGA) IC 170 2764800 52160 256-LBGA Check availability

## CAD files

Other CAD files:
2_Functional Diagram & Interconnection Matrices/Functional_Diagram.dwg

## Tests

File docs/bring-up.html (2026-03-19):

AERIS-10 Docs

Execution Checklist

# Hardware Bring-Up Plan

Pre-arrival completeness gates, board-day smoke tests, and fault-localization rules for the first FPGA module and carrier-board sessions.

Open Board-Day Worksheet Open Artifact Inventory

## Pre-arrival completeness gates

Gate | Objective | Pass Criteria | Evidence
1 | Freeze known-good firmware and bitstream baselines | Tracked commit, named artifact set, and repeatable programming flow are available | Git commit, bitstream path, reports, programming TCL
2 | Preserve clean implementation constraints | Positive WNS/WHS/WPWS, XDCB-5 cleared, only documented methodology residue remains | Timing summary and methodology report
3 | Keep regressions green before board arrival | MCU host tests and FPGA regression/integration suites pass on the tracked tree | 15/15 MCU and 18/18 FPGA logs
4 | Make first-power-on behavior observable | Clock, LO, beamformer, PA, and USB status can be identified from logs or status outputs | DIAG coverage, status fields, ILA/debug plan
5 | Prepare board-arrival execution checklist | Power order, abort criteria, and host-side capture steps are written and reviewed | This page plus reports and scripts references
6 | Document unresolved pre-hardware risks | Open issues are explicitly listed so Day-0 findings are interpreted correctly | Known-open-risks section below

## Board-arrival smoke test

1. Inspect carrier defaults, regulator enables, jumpers, and any board-level clock source selections before power is applied.
2. Power the carrier and module in the safest configuration with RF transmit paths disabled and document current draw immediately.
3. Run the FPGA programming flow, verify JTAG enumeration, and confirm DONE and INIT_COMPLETE from the hardware manager script.
4. Check deterministic reset release and heartbeat/status outputs before enabling any analog or RF-dependent function.
5. Bring up MCU firmware logging, confirm AD9523 status pins, LO initialization results, and beamformer communication readback.
6. Use the debug-capable FPGA image and probes to confirm raw ADC, DDC, matched-filter, and USB-path activity in that order.
7. Exercise the FT601 path with known framing expectations before any long-duration streaming test.
8. Only after all previous steps pass, begin PA bias, calibration, and higher-risk RF activation.

## Abort criteria

- Stop immediately on unexpected rail current, regulator instability, or thermal rise beyond the planned idle envelope.
- Do not continue past LO bring-up if the lock GPIOs or lock-status reads disagree repeatedly.
- Stop RF activation if beamformer scratchpad/readback checks fail on any device.
- Do not continue USB stress testing if framing, backpressure, or bus-direction behavior is inconsistent.
- Revert to the heartbeat or debug image if reset sequencing or clock presence is ambiguous.
- Keep the production-target constraints and pinout source untouched while bring-up-specific targets are being adjusted.

## First-power-on observability targets

Subsystem | What must be visible | Expected evidence
FPGA configuration | JTAG enumeration, DONE, INIT_COMPLETE, optional ILA probe presence | program_fpga.tcl summary and hardware-manager status
Clocking | AD9523 status pins and deterministic downstream reset release | DIAG clock messages and status GPIO snapshots
LO chain | ADF4382A init status, timed-sync path status, TX/RX lock state | USART3 DIAG log plus lock GPIO behavior
Beamformer control | Per-device communication sanity and basic temperature readback | ADAR1000 scratchpad/readback and temperature prints
PA biasing | DAC/ADC bring-up progression and IDQ calibration convergence bounds | Per-channel PA DIAG output with stop conditions
FPGA data path | ADC, DDC, matched-filter, and USB-path activity in sequence | ILA captures and system status outputs
USB/FT601 link | Stable framing, no obvious underrun/backpressure surprises, host decode sanity | Host capture script output and stable packet boundaries

## Required artifacts before hardware arrives

- Named firmware baseline commit and build instructions for the MCU image.
- Named FPGA baseline bitstream and matching `.ltx` probes file for debug sessions.
- Current production-target XDC, timing summary, and methodology report.
- Programming and debug TCL scripts for baseline and debug images.
- Regression evidence for the tracked branch: MCU host suite and FPGA regression/integration suite.
- Day-0 measurement sheet covering supply currents, temperatures, and observed status outputs.

View concrete artifact inventory

## Host-side tools and workflows

- JTAG programming workflow using the checked-in Vivado TCL scripts.
- Serial capture on USART3 with timestamps preserved for bring-up logs.
- FT601 or host-side USB capture/decoder workflow to validate framing and payload stability.
- ILA capture workflow for raw ADC, DDC, matched-filter, and USB-domain checkpoints.
- Repeatable checklist for baseline image, debug image, and rollback image selection.

Open printable worksheet

## Known open risks before board arrival

Risk | Current state | Day-0 handling
Residual FT601 methodology warning | Production-target XDC cleanup is validated, but one `ft601_txe` methodology residue remains documented. | Treat as a known observation item and verify real FT601 status behavior before attempting deeper constraint churn.
RF control-path realism | Firmware sequencing and diagnostics improved, but LO sync, phase behavior, and beamformer control still require physical validation. | Use readback-first bring-up and do not assume analog behavior from simulation or logs alone.
Prototype-grade top-level functional assumptions | The active FPGA baseline is regression-clean, but some radar-function behavior still needs real-board confirmation under actual I/O conditions. | Validate each data-path stage incrementally with ILA and host captures before full streaming claims.
PA calibration boundaries | IDQ calibration logic is much safer than before, but real-device convergence and margin limits are not yet board-proven. | Use conservative limits, observe every channel, and stop on abnormal current or non-convergent channels.
Board-specific integration unknowns | Carrier/module interaction, rails, clocks, and connector assumptions remain partially unproven until first assembly. | Begin with lowest-risk heartbeat and configuration checks before enabling higher-energy subsystems.

This page is the operational source of truth for pre-arrival readiness and first-power-on execution.

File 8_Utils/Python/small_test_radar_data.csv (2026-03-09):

timestamp_ns | chirp_number | chirp_type | sample_index | I_value | Q_value | magnitude_squared
0 | 0 | LONG | 0 | -4 | 2 | 31
2 | 0 | LONG | 1 | 3 | -3 | 19
4 | 0 | LONG | 2 | 0 | 0 | 0
6 | 0 | LONG | 3 | -3 | 0 | 16
8 | 0 | LONG | 4 | -1 | -6 | 41
10 | 0 | LONG | 5 | 0 | 6 | 41
12 | 0 | LONG | 6 | -2 | 0 | 4
14 | 0 | LONG | 7 | -5 | 4 | 50
16 | 0 | LONG | 8 | 4 | -2 | 26
18 | 0 | LONG | 9 | 0 | -1 | 2
20 | 0 | LONG | 10 | 3 | 1 | 14
22 | 0 | LONG | 11 | 2 | -2 | 12
24 | 0 | LONG | 12 | -1 | 0 | 2
26 | 0 | LONG | 13 | 0 | -1 | 1
28 | 0 | LONG | 14 | -2 | 0 | 5
30 | 0 | LONG | 15 | 0 | 5 | 26
32 | 0 | LONG | 16 | -1 | 1 | 6
34 | 0 | LONG | 17 | -4 | 0 | 23
36 | 0 | LONG | 18 | 0 | 0 | 0
38 | 0 | LONG | 19 | -3 | -4 | 32
40 | 0 | LONG | 20 | -2 | 0 | 5
42 | 0 | LONG | 21 | 0 | -4 | 18
44 | 0 | LONG | 22 | -2 | 0 | 4
46 | 0 | LONG | 23 | 1 | -3 | 14
48 | 0 | LONG | 24 | 1 | -1 | 5
50 | 0 | LONG | 25 | 3 | 3 | 26
52 | 0 | LONG | 26 | 0 | 3 | 10
54 | 0 | LONG | 27 | -4 | -2 | 27
56 | 0 | LONG | 28 | 2 | 0 | 5
58 | 0 | LONG | 29 | 0 | -5 | 25
60 | 0 | LONG | 30 | -2 | 1 | 8
62 | 0 | LONG | 31 | 0 | 0 | 0
64 | 0 | LONG | 32 | -3 | -3 | 22
66 | 0 | LONG | 33 | 0 | 0 | 1
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

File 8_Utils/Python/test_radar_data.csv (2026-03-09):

timestamp_ns | chirp_number | chirp_type | sample_index | I_value | Q_value | magnitude_squared
0 | 0 | LONG | 0 | -15 | 16 | 499
2 | 0 | LONG | 1 | -12 | 17 | 484
4 | 0 | LONG | 2 | 0 | 9 | 94
6 | 0 | LONG | 3 | -12 | -8 | 228
8 | 0 | LONG | 4 | -2 | -4 | 26
10 | 0 | LONG | 5 | -10 | -2 | 124
12 | 0 | LONG | 6 | -4 | -13 | 195
14 | 0 | LONG | 7 | -3 | -5 | 44
16 | 0 | LONG | 8 | -12 | 14 | 356
18 | 0 | LONG | 9 | -3 | -5 | 40
20 | 0 | LONG | 10 | 0 | -8 | 76
22 | 0 | LONG | 11 | -11 | 26 | 846
24 | 0 | LONG | 12 | -7 | 1 | 53
26 | 0 | LONG | 13 | -10 | 10 | 216
28 | 0 | LONG | 14 | 3 | -3 | 27
30 | 0 | LONG | 15 | 21 | 8 | 517
32 | 0 | LONG | 16 | 17 | 3 | 317
34 | 0 | LONG | 17 | 15 | -5 | 279
36 | 0 | LONG | 18 | 29 | -1 | 886
38 | 0 | LONG | 19 | -16 | 0 | 268
40 | 0 | LONG | 20 | -6 | -9 | 129
42 | 0 | LONG | 21 | 0 | 0 | 0
44 | 0 | LONG | 22 | -5 | 1 | 30
46 | 0 | LONG | 23 | 12 | 11 | 300
48 | 0 | LONG | 24 | 10 | 1 | 116
50 | 0 | LONG | 25 | -5 | -14 | 255
52 | 0 | LONG | 26 | -2 | 3 | 18
54 | 0 | LONG | 27 | 0 | 11 | 135
56 | 0 | LONG | 28 | 9 | 19 | 466
58 | 0 | LONG | 29 | 15 | 6 | 280
60 | 0 | LONG | 30 | -13 | 4 | 187
62 | 0 | LONG | 31 | 2 | -8 | 76
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

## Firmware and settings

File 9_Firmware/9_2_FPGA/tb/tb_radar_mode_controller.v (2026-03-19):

`timescale 1ns / 1ps

module tb_radar_mode_controller;

    // ── Parameters ─────────────────────────────────────────────
    localparam CLK_PERIOD = 10.0;  // 100 MHz

    // Use much shorter timing for simulation (100x faster)
    localparam SIM_LONG_CHIRP   = 30;
    localparam SIM_LONG_LISTEN  = 137;
    localparam SIM_GUARD        = 175;
    localparam SIM_SHORT_CHIRP  = 5;
    localparam SIM_SHORT_LISTEN = 175;

    // Use small scan size for simulation
    localparam SIM_CHIRPS     = 4;
    localparam SIM_ELEVATIONS = 3;
    localparam SIM_AZIMUTHS   = 2;

    // ── Signals ────────────────────────────────────────────────
    reg         clk;
    reg         reset_n;
    reg  [1:0]  mode;
    reg         stm32_new_chirp;
    reg         stm32_new_elevation;
    reg         stm32_new_azimuth;
    reg         trigger;

    // Gap 2: Runtime-configurable timing inputs
    reg  [15:0] cfg_long_chirp_cycles;
    reg  [15:0] cfg_long_listen_cycles;
    reg  [15:0] cfg_guard_cycles;
    reg  [15:0] cfg_short_chirp_cycles;
    reg  [15:0] cfg_short_listen_cycles;
    reg  [5:0]  cfg_chirps_per_elev;

    wire        use_long_chirp;
    wire        mc_new_chirp;
    wire        mc_new_elevation;
    wire        mc_new_azimuth;
    wire [5:0]  chirp_count;
    wire [5:0]  elevation_count;
    wire [5:0]  azimuth_count;
    wire        scanning;
    wire        scan_complete;

    // ── Test bookkeeping ───────────────────────────────────────
    integer pass_count;
    integer fail_count;
    integer test_num;
    integer csv_file;
    integer i;

    // Edge detection helpers for auto-scan counting
    reg mc_new_chirp_prev;
    reg mc_new_elevation_prev;
    reg mc_new_azimuth_prev;
    integer chirp_toggles;
    integer elevation_toggles;
    integer azimuth_toggles;
    integer scan_completes;

    // Saved values for toggle checks
    reg saved_mc_new_chirp;
    reg saved_mc_new_elevation;
    reg saved_mc_new_azimuth;

    // ── Clock ──────────────────────────────────────────────────
    always #(CLK_PERIOD/2) clk = ~clk;

    // ── DUT ────────────────────────────────────────────────────
    radar_mode_controller #(
        .CHIRPS_PER_ELEVATION  (SIM_CHIRPS),
        .ELEVATIONS_PER_AZIMUTH(SIM_ELEVATIONS),
        .AZIMUTHS_PER_SCAN     (SIM_AZIMUTHS),
        .LONG_CHIRP_CYCLES     (SIM_LONG_CHIRP),
        .LONG_LISTEN_CYCLES    (SIM_LONG_LISTEN),
        .GUARD_CYCLES          (SIM_GUARD),
        .SHORT_CHIRP_CYCLES    (SIM_SHORT_CHIRP),
        .SHORT_LISTEN_CYCLES   (SIM_SHORT_LISTEN)
    ) uut (
        .clk                (clk),
        .reset_n            (reset_n),
        .mode               (mode),
        .stm32_new_chirp    (stm32_new_chirp),
        .stm32_new_elevation(stm32_new_elevation),
        .stm32_new_azimuth  (stm32_new_azimuth),
        .trigger            (trigger),
        // Gap 2: Runtime-configurable timing inputs
        .cfg_long_chirp_cycles  (cfg_long_chirp_cycles),
        .cfg_long_listen_cycles (cfg_long_listen_cycles),
        .cfg_guard_cycles       (cfg_guard_cycles),
        .cfg_short_chirp_cycles (cfg_short_chirp_cycles),
        .cfg_short_listen_cycles(cfg_short_listen_cycles),
        .cfg_chirps_per_elev    (cfg_chirps_per_elev),
        // Outputs
        .use_long_chirp     (use_long_chirp),
        .mc_new_chirp       (mc_new_chirp),
        .mc_new_elevation   (mc_new_elevation),
        .mc_new_azimuth     (mc_new_azimuth),
        .chirp_count        (chirp_count),
        .elevation_count    (elevation_count),
        .azimuth_count      (azimuth_count),
        .scanning           (scanning),
        .scan_complete      (scan_complete)
    );

    // ── Check task ─────────────────────────────────────────────
    task check;
        input cond;
        input [511:0] label;
        begin
            test_num = test_num + 1;
            if (cond) begin
                $display("[PASS] Test %0d: %0s", test_num, label);
                pass_count = pass_count + 1;
            end else begin
                $display("[FAIL] Test %0d: %0s", test_num, label);
                fail_count = fail_count + 1;
            end
        end
    endtask

    // ── Helper: apply reset ────────────────────────────────────
    task apply_reset;
        begin
            reset_n             = 0;
            mode                = 2'b11;  // reserved = safe idle
            stm32_new_chirp     = 0;
            stm32_new_elevation = 0;
            stm32_new_azimuth   = 0;
            trigger             = 0;
            // Gap 2: Set cfg_* to simulation parameter defaults
            cfg_long_chirp_cycles  = SIM_LONG_CHIRP;
            cfg_long_listen_cycles = SIM_LONG_LISTEN;
            cfg_guard_cycles       = SIM_GUARD;
            cfg_short_chirp_cycles = SIM_SHORT_CHIRP;
            cfg_short_listen_cycles = SIM_SHORT_LISTEN;
            cfg_chirps_per_elev    = SIM_CHIRPS;
            repeat (4) @(posedge clk);
            reset_n = 1;
            @(posedge clk); #1;
        end
    endtask

    // ── Stimulus ───────────────────────────────────────────────
    initial begin
        $dumpfile("tb_radar_mode_controller.vcd");
        $dumpvars(0, tb_radar_mode_controller);

        clk        = 0;
        pass_count = 0;
        fail_count = 0;
        test_num   = 0;

        // ════════════════════════════════════════════════════════
        // TEST GROUP 1: Reset behaviour
        // ════════════════════════════════════════════════════════
        $display("\n--- Test Group 1: Reset Behaviour ---");
        apply_reset;

        reset_n = 0;
        repeat (4) @(posedge clk); #1;
        check(use_long_chirp === 1'b1,     "use_long_chirp=1 after reset");
        check(mc_new_chirp === 1'b0,       "mc_new_chirp=0 after reset");
        check(mc_new_elevation === 1'b0,   "mc_new_elevation=0 after reset");
        check(mc_new_azimuth === 1'b0,     "mc_new_azimuth=0 after reset");
        check(chirp_count === 6'd0,        "chirp_count=0 after reset");
        check(elevation_count === 6'd0,    "elevation_count=0 after reset");
        check(azimuth_count === 6'd0,      "azimuth_count=0 after reset");
        check(scanning === 1'b0,           "scanning=0 after reset");
        check(scan_complete === 1'b0,      "scan_complete=0 after reset");
        reset_n = 1;
        @(posedge clk); #1;

        // ════════════════════════════════════════════════════════
        // TEST GROUP 2: STM32 pass-through mode (mode 00)
        // The DUT uses XOR toggle detection: when stm32_new_chirp
        // changes from its previous value, the DUT detects it.
        // We toggle-and-hold (don't pulse) to get exactly one detection.
        // ════════════════════════════════════════════════════════
        $display("\n--- Test Group 2: STM32 Pass-through (mode 00) ---");
        apply_reset;
        mode = 2'b00;
        @(posedge clk); #1;

        // Save current mc_new_chirp
        saved_mc_new_chirp = mc_new_chirp;
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

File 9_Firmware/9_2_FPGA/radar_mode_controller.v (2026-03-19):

`timescale 1ns / 1ps

/**
 * radar_mode_controller.v
 *
 * Generates beam scanning and chirp mode control signals for the AERIS-10
 * receiver processing chain. This module drives:
 *   - use_long_chirp   : selects long (30us) or short (0.5us) chirp mode
 *   - mc_new_chirp     : toggle signal indicating new chirp start
 *   - mc_new_elevation : toggle signal indicating elevation step
 *   - mc_new_azimuth   : toggle signal indicating azimuth step
 *
 * These signals are consumed by matched_filter_multi_segment and
 * chirp_memory_loader_param in the receiver path.
 *
 * The controller mirrors the transmitter's chirp sequence defined in
 * plfm_chirp_controller_enhanced:
 *   - 32 chirps per elevation
 *   - 31 elevations per azimuth
 *   - 50 azimuths per full scan
 *   - Each chirp: Long chirp → Listen → Guard → Short chirp → Listen
 *
 * Modes of operation:
 *   mode[1:0]:
 *     2'b00 = STM32-driven (pass through stm32 toggle signals)
 *     2'b01 = Free-running auto-scan (internal timing)
 *     2'b10 = Single-chirp (fire one chirp per trigger, for debug)
 *     2'b11 = Reserved
 *
 * Clock domain: clk (100 MHz)
 */

module radar_mode_controller #(
    parameter CHIRPS_PER_ELEVATION = 32,
    parameter ELEVATIONS_PER_AZIMUTH = 31,
    parameter AZIMUTHS_PER_SCAN = 50,

    // Timing in 100 MHz clock cycles
    // Long chirp: 30us = 3000 cycles at 100 MHz
    // Long listen: 137us = 13700 cycles
    // Guard: 175.4us = 17540 cycles
    // Short chirp: 0.5us = 50 cycles
    // Short listen: 174.5us = 17450 cycles
    parameter LONG_CHIRP_CYCLES   = 3000,
    parameter LONG_LISTEN_CYCLES  = 13700,
    parameter GUARD_CYCLES        = 17540,
    parameter SHORT_CHIRP_CYCLES  = 50,
    parameter SHORT_LISTEN_CYCLES = 17450
) (
    input wire clk,
    input wire reset_n,

    // Mode selection
    input wire [1:0] mode,          // 00=STM32, 01=auto, 10=single, 11=rsvd

    // STM32 pass-through inputs (active in mode 00)
    input wire stm32_new_chirp,
    input wire stm32_new_elevation,
    input wire stm32_new_azimuth,

    // Single-chirp trigger (active in mode 10)
    input wire trigger,

    // Gap 2: Runtime-configurable timing inputs from host USB commands.
    // When connected, these override the compile-time parameters.
    // When left at default (tied to parameter values at instantiation),
    // behavior is identical to pre-Gap-2.
    input wire [15:0] cfg_long_chirp_cycles,
    input wire [15:0] cfg_long_listen_cycles,
    input wire [15:0] cfg_guard_cycles,
    input wire [15:0] cfg_short_chirp_cycles,
    input wire [15:0] cfg_short_listen_cycles,
    input wire [5:0]  cfg_chirps_per_elev,

    // Outputs to receiver processing chain
    output reg use_long_chirp,
    output reg mc_new_chirp,
    output reg mc_new_elevation,
    output reg mc_new_azimuth,

    // Beam position tracking
    output reg [5:0] chirp_count,
    output reg [5:0] elevation_count,
    output reg [5:0] azimuth_count,

    // Status
    output wire scanning,       // 1 = scan in progress
    output wire scan_complete   // pulse when full scan done

`ifdef FORMAL
    ,
    output wire [2:0]  fv_scan_state,
    output wire [17:0] fv_timer
`endif
);

// ============================================================================
// INTERNAL STATE
// ============================================================================

// Auto-scan state machine
reg [2:0] scan_state;
localparam S_IDLE        = 3'd0;
localparam S_LONG_CHIRP  = 3'd1;
localparam S_LONG_LISTEN = 3'd2;
localparam S_GUARD       = 3'd3;
localparam S_SHORT_CHIRP = 3'd4;
localparam S_SHORT_LISTEN = 3'd5;
localparam S_ADVANCE     = 3'd6;

// Timing counter
reg [17:0] timer;  // enough for up to 262143 cycles (~2.6ms at 100 MHz)

`ifdef FORMAL
assign fv_scan_state = scan_state;
assign fv_timer      = timer;
`endif

// Edge detection for STM32 pass-through
reg stm32_new_chirp_prev;
reg stm32_new_elevation_prev;
reg stm32_new_azimuth_prev;

// Trigger edge detection (for single-chirp mode)
reg trigger_prev;
wire trigger_pulse = trigger & ~trigger_prev;

// Scan completion
reg scan_done_pulse;

// ============================================================================
// EDGE DETECTION
// ============================================================================
always @(posedge clk or negedge reset_n) begin
    if (!reset_n) begin
        stm32_new_chirp_prev     <= 1'b0;
        stm32_new_elevation_prev <= 1'b0;
        stm32_new_azimuth_prev   <= 1'b0;
        trigger_prev             <= 1'b0;
    end else begin
        stm32_new_chirp_prev     <= stm32_new_chirp;
        stm32_new_elevation_prev <= stm32_new_elevation;
        stm32_new_azimuth_prev   <= stm32_new_azimuth;
        trigger_prev             <= trigger;
    end
end

wire stm32_chirp_toggle     = stm32_new_chirp     ^ stm32_new_chirp_prev;
wire stm32_elevation_toggle = stm32_new_elevation  ^ stm32_new_elevation_prev;
wire stm32_azimuth_toggle   = stm32_new_azimuth    ^ stm32_new_azimuth_prev;
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

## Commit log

2026-03-08 Add files via upload
    Project structure
    [Functional_Diagram.dwg, Power Management.xlsx]
2026-03-15 Fix CDC timing violations: add synchronizers for all inter-clock crossings
    Resolve all 4 inter-clock timing violations found in Vivado synthesis
    attempt #11 (WNS was -2.552 ns). Changes:
    - Add reset synchronizer for clk_120m_dac domain (2-FF chain)
    - Add Gray-code CDC for chirp_counter (6-bit, 120MHz->100MHz)
    - Add single-bit CDC for new_chirp_frame (3-stage, 120MHz->100MHz)
    - Add 2-stage input synchronizers for valid signals in USB module
    (clk_100m->ft601_clk_in) with data capture on rising edge
    - Fix ft601_clk_out multi-driven net (removed duplicate assignment)
    - Update XDC: set_max_delay -datapath_only for CDC, false_path for reset
    Result: Vivado attempt #12 passes with 0 errors, 0 ti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
2026-03-17 Convert async→sync reset on DSP/BRAM datapath registers for timing closure
    P1-CRITICAL: doppler_processor.v — split FSM into control (async reset)
    and BRAM/DSP datapath (sync reset) blocks. Fixes REQP-1839/1840 BRAM
    address register corruption risk; enables DSP48 absorption of window
    multipliers (mult_i/q).
    P1-CRITICAL: frequency_matched_filter.v — convert all 4 pipeline stages
    (input capture, multiply, add, saturate) from async to sync reset.
    Enables DSP48E1 absorption of complex multiplier registers.
    P1-HIGH: fir_lowpass.v — convert adder tree (L0-L4), output stage, and
    valid pipeline from async to sync reset. Fixes 856 DPOR-1 warnings
    (428 per FIR instance × 2 I/Q channels), en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
2026-03-19 Add board-day worksheet and cross-link bring-up docs
2026-03-19 Gap 2 GUI Settings: runtime chirp timing, stream control gating, status readback (18/18 FPGA, 20/20 MCU)
    Register map: 0x10-0x15 chirp timing overrides, 0xFF status readback,
    0x03 CFAR threshold now wired to actual compare, 0x04 stream control
    gates USB write FSM. Status readback sends 7-word packet (0xBB header,
    5 status words, 0x55 footer) via toggle CDC.
    radar_mode_controller: 6 cfg_* input ports replace hardcoded parameters.
    usb_data_interface: stream_control CDC, status_request toggle CDC,
    SEND_STATUS state (3'd7), stream gating in IDLE/HEADER/RANGE/DOPPLER.
    radar_system_top: 6 host registers + command decode for 0x10-0x15/0xFF.
    radar_receiver_final: 6 host_* timing passthrough ports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
    [radar_mode_controller.v, tb_radar_mode_controller.v]

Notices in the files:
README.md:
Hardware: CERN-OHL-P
